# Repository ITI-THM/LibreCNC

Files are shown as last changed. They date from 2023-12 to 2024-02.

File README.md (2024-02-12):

# LibreCNC

## Introduction

LibreCNC is a 100% open source circuit board repository for stepper driver powered CNC Machines of any kind. The circuit boards are designed to be modular with documented interfaces in between the boards.

Please check the [Success Stories](./Success%20Stories/) for a reference on how these boards can be used.

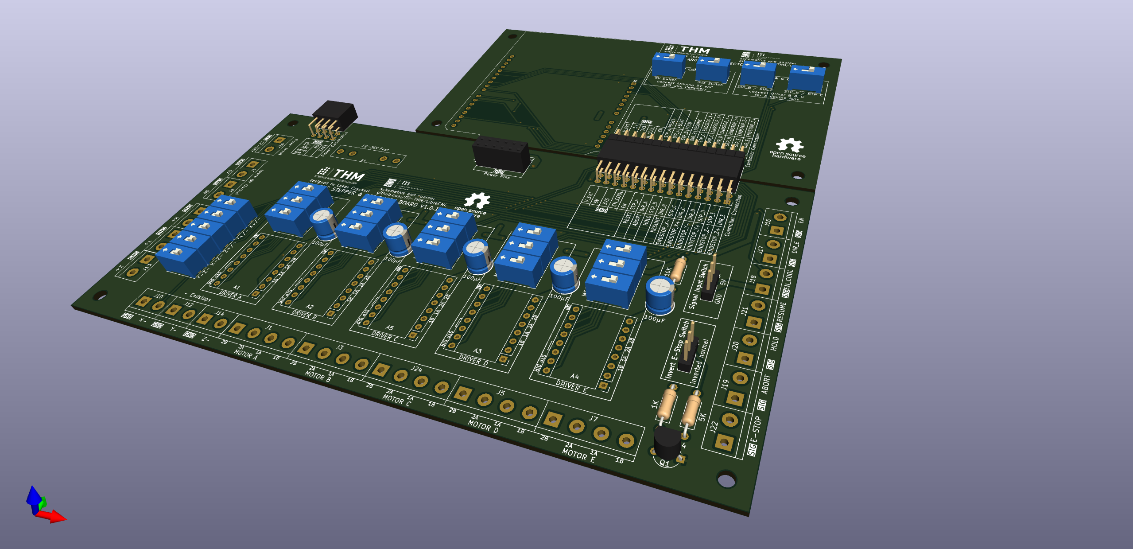
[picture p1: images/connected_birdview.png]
connected_birdview


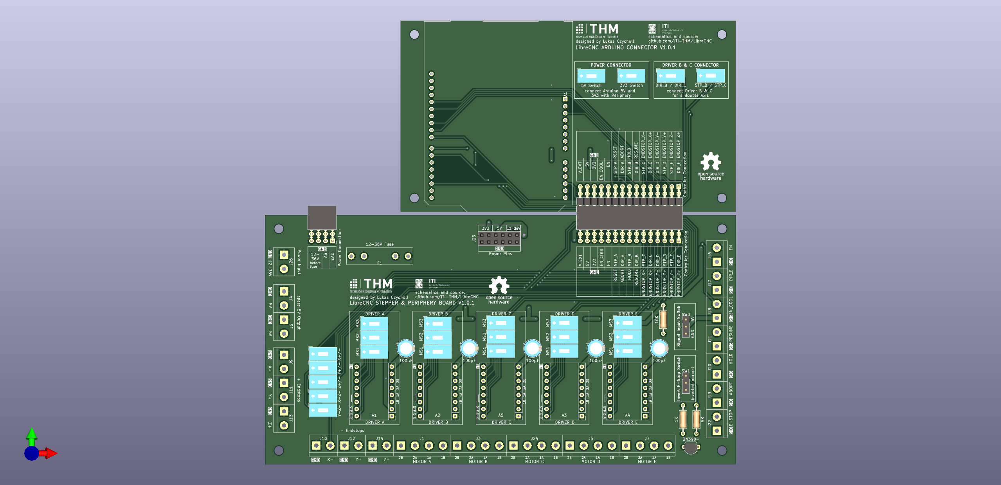
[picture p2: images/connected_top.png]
connected_top


## Circuit Boards

The main modular circuit board is seperated in 3 parts:
- a [periphery board](#periphery-board) for stepper drivers, endstops and buttons
- a [logic board](#logic-board) for a (micro)controller
- a [power board](#power-board) for a stable power supply (tbd)

These parts have fixed interfaces that might be altered whenever a main version is changed (eg. from V1.x to V2.x).

### periphery board

current variations:
- [periphery_5_drivers](./periphery_5_drivers/README.md)

### logic board

current variations:
- [arduino-uno-connector](./arduino-uno-connector/README.md)

### power board

current variations:
None

Additionally these boards were created for specific tasks:
- [arduino pwm fan control board](./fan-control/README.md)

## Repository Structure

Each Circuit Board is designed with [KiCad](https://www.kicad.org/). 

The boards are stored within a directory with the corrsponding name.

Each directory consists of:
- a project file (.kicad_pro)
- a schematic file (.kicad_sch)
- a pcb file (.kicad_pcb)
- a gerber file directory storing gerber files of the finished versions
- a readme giving details about the board
- a picture of a 3D View of the board
- OPTIONAL: a list of parts

## Licencing 

All Circuit Boards are Licenced with the MIT Licence. Feel free to fork and experiment with the schematics and pcbs as you want.

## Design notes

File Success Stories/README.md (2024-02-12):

# Success Stories

This folder holds reference projects to to use as a guideline when using the libreCNC boards

* [Stepcraft 840 V1 Success Story](./Stepcraft%20840/Stepcraft840Story.md)

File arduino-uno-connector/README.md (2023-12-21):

# Arduino Connector

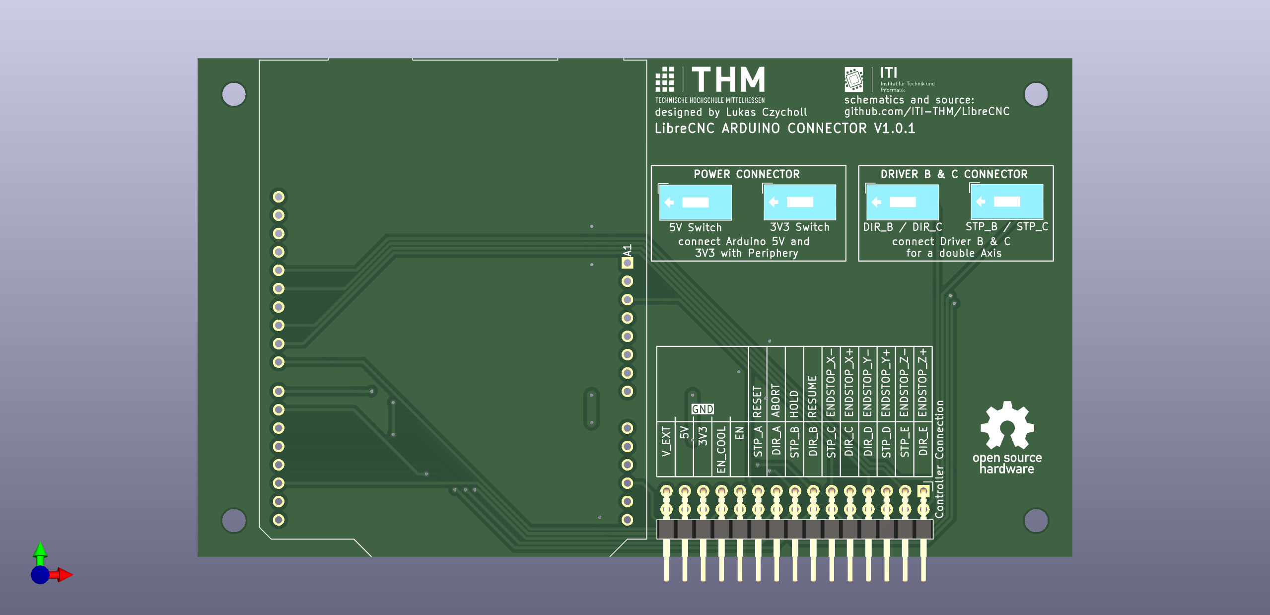
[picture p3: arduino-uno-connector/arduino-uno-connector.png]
arduino-uno-connector


This board is connecting an arduino uno with the periphery board. 
It is designed to be used with [grbl](https://github.com/gnea/grbl) as running software.
Therefore the grbl pinouts are used.

## Driver Usage

- Driver A: X Axis
- Driver B: Y Axis (can be extended with Driver C for a Dual Axis)
- Driver D: Z Axis
- Driver E: Spindle

## Additional Infos

Please be aware of the following things:

- as long as the periphery board has no 5V or 3V3 Input, the 5V and 3V3 of the Arduino can be used.
- the board is designed in a way that the usb port is avaliable at the top of the board. If mounting within limited space be aware that the USB Port is outside the board size.

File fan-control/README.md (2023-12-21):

# arduino pwm fan control

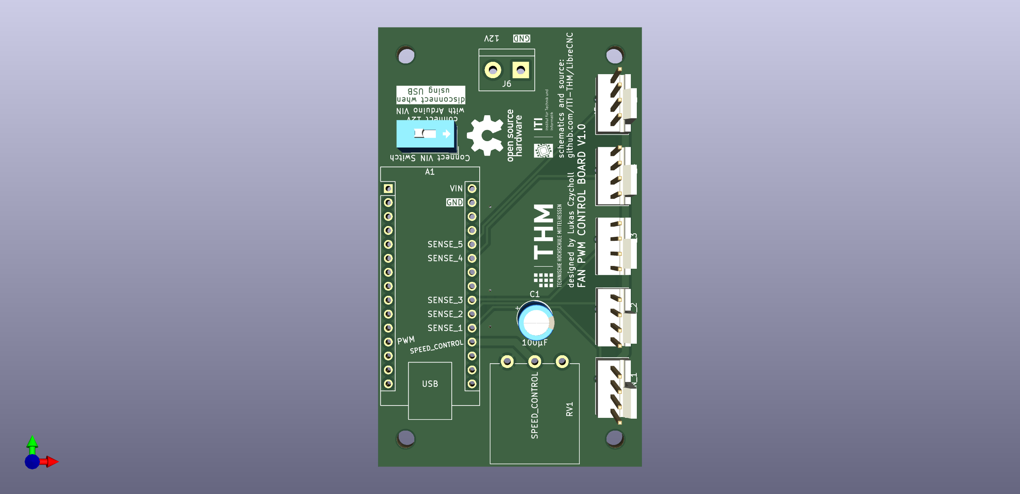
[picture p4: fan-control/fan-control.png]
fan-control


A board designed to hold an arduino nano, a potentiometer and control up to 5 pwm fans

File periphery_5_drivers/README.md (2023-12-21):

# Periphery 5 Drivers

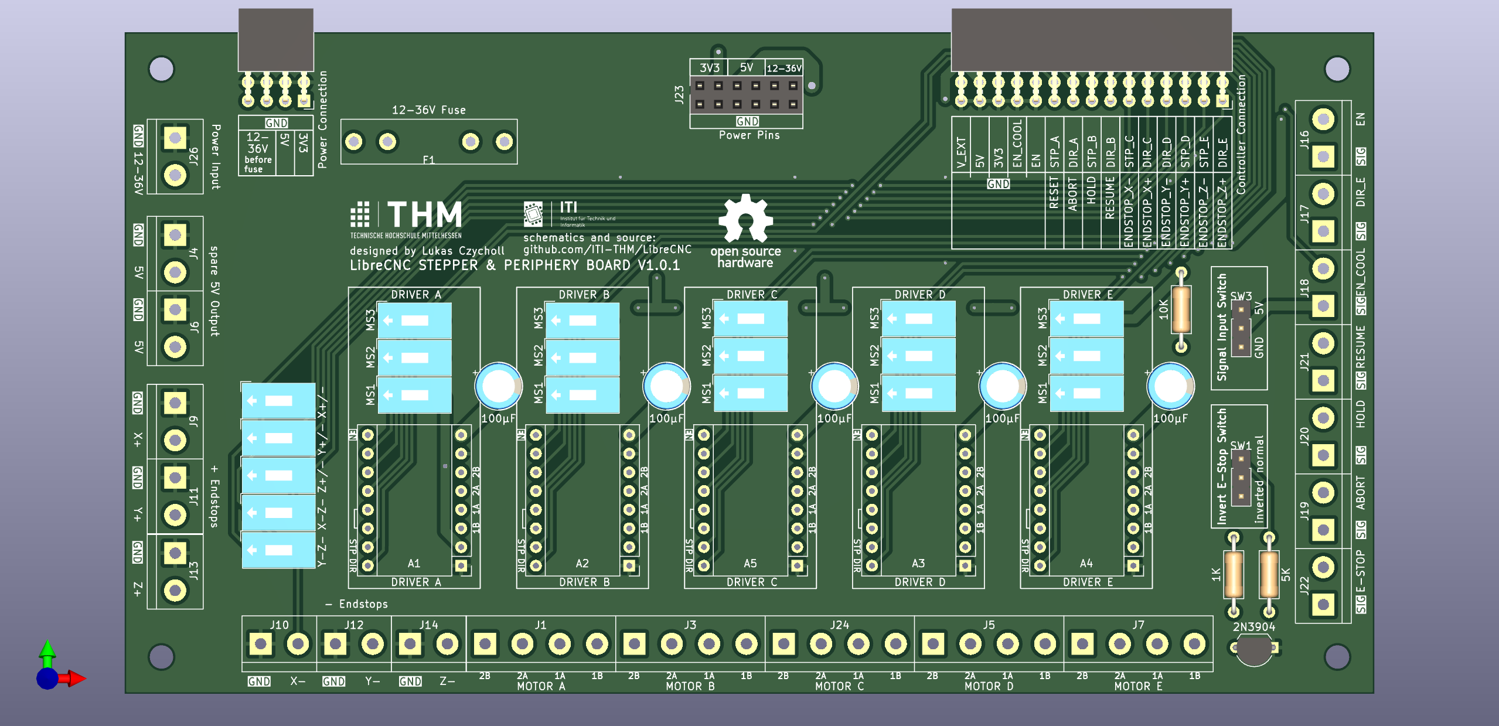
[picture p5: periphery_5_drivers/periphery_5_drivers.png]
periphery_5_drivers


This board is holding periphery for the following:
- 5 stepper drivers
- 6 Endstops
- 5 Buttons
- signal forwarding
- power connections

## stepper drivers

The board is designed for A4988 drivers. 
Therefore any compatabile driver (like the TMC2209) can be used with this board.

## Endstops

the following (basic) endstops are supported:
- X+
- X-
- Y+
- Y-
- Z+
- Z-

Additionally there are switches to connect several endstops in order to be more compatible with different controllers.

- Y- to Z- and X- to Z- can be connected (as it is needed for specific machines)
- X-,Y- & Z- can be connected to the + part to use only one logic signal for both endstops

## Buttons

these buttons are supported:
- E-Stop
- Abort
- Hold
- Resume

The E-Stop signal can be inverted with a hardware switch.

To connect different buttons the signal can be connected to either 5V or GND

## Signal Forwarding

the following signals can be used by external periphery:
- EN
- DIR_E (eg. for an external Spindle)
- EN_COOL (eg. for an external Spindle)

## power connections

### Input: 
When using the periphery board without a power board, the power input screw connection can be used.
This input (as well as the power board input) is secured by a basic fuse.

### Output:
The board has the following power output connections:
- 2x 5V Screw Terminals
- 2x 12-36V Pins
- 2x 5V Pins
- 2x 3V3 Pins

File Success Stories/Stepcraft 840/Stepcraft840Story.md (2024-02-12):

# Stepcraft 840 V1 Success Story
**Replacing the original Board with an OpenSource**

- [Stepcraft 840 V1 Success Story](#stepcraft-840-v1-success-story)
  - [disclaimer](#disclaimer)
  - [Introduction](#introduction)
  - [the default board](#the-default-board)
  - [setting up the libreCNC Board with an arduino UNO](#setting-up-the-librecnc-board-with-an-arduino-uno)
    - [getting everything together](#getting-everything-together)
    - [setting up the board](#setting-up-the-board)
    - [exchanging with the libreCNC Board](#exchanging-with-the-librecnc-board)
  - [setting up the software](#setting-up-the-software)
  - [Conclusion](#conclusion)
  - [Optional: Cover](#optional-cover)
  - [Optional: Fans](#optional-fans)

## disclaimer
altering the Stepcraft 840 with this guide is your responsibility. Please take care of all necessary safety measures and be aware that I as the writer take no responsibility for your health or the health of the machine. Please be aware that your own thinking and basic knowledge and understanding is needed for this guide to be successfull. 

Please also open an issue if you are stuck on any part of this guide or if you were misguided. Thank you for your participation.

## Introduction

The Stepcraft 840 is a hobby milling machine featuring 3 Axis driven by Stepper Drivers, Endstops and (optional) a milling head or any tool. It basically has the same default setup as a 3D Printer.

Currently the Stepcraft 840 is only avaliable in a second revision as the first one had several issues. 
But both versions lack the features of an open source project and thats what this story is changing.

## the default board

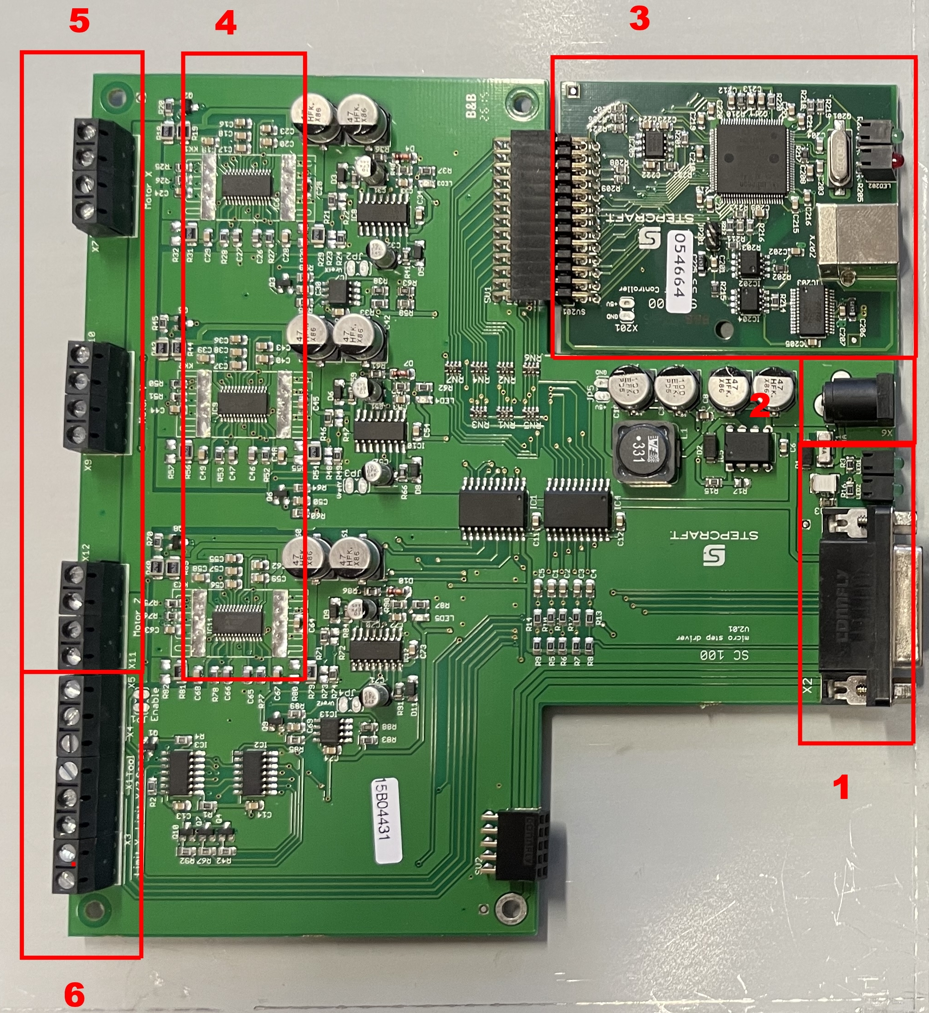
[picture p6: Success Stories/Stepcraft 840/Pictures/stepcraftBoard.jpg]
stepcraft board


When ordering a Stepcraft 840, it ships with a commercial board to control the machine. The board features the following things:

1. RS232 connection for direct communication
2. 12V Barrel Jack Port
3. (optional) USB B Port for indirect communication. (only works with specific software)
4. soldered in stepper drivers
5. 3 stepper driver connections for each axis
6. endstop connections

The board is designed to work with specific proprietary control software which renders the whole board useless if the software is not avaliable or does not satisfy the needs of the user.

## setting up the libreCNC Board with an arduino UNO

### getting everything together
You need the [periphery 5 drivers](../../periphery_5_drivers/README.md) and the [arduino uno connector](../../arduino-uno-connector/README.md) board.

You also need 3 (4 with dual y Axis) stepper drivers. Prefereed are [TMC2208](https://github.com/bigtreetech/BIGTREETECH-TMC2208-V3.0), but any driver with the same basic behavior as the [A4988](https://www.pololu.com/product/1182) works.

With this setup you also need an [Arduino Uno](https://store.arduino.cc/products/arduino-uno-rev3).

### setting up the board

Connect the Arduino Uno with the Arduino Uno Board. You need to enable the Power Connection 5V Switch as this setup only provides the main voltage (12-36V) to the drivers and needs the 5V logical voltage from the arduino.

Then insert the stepper drivers into a, b and c (and d with dual Y Axis) into the slots.

### exchanging with the libreCNC Board

The libreCNC Board Version 1.0.1 is specifically designed to fit within the same slot as the commercial stepcraft board.
It also features almost all peripherals as the commcercial alternative. 

libreCNC & stepcraft comparision

This is how you can connect everything:

* place any non electrically conductive material like a tape on the inside of the metal cover hiding the circuit board within the stepcraft 840.
* 1,2,3: connect the stepper motors from stepcraft x,y,z to libreCNC a,b,d. (if your stepcraft has to y motors, connect the second one to c)
* 4: connect the y endstop connection into y- and the x endstop connection into x-. Also switch the x-/z- switch if no specific cable for the z endstop is avaliable. This means the x and z endstop are connected to the same cable within the milling machine.
* 5: The current libreCNC setup does not provide a Barrel Jack. So instead you need to connect the main Power with screw connectors 

**WARNING: USE AN ELECTRICALLY CONDUCTIVE MATERIAL ON THE INSIDE OF THE METAL COVER**

## setting up the software

With this setup it is preferred to use [grbl](https://github.com/gnea/grbl) to control the machine.

Please use the latest [tutorial](https://github.com/gnea/grbl/wiki/Compiling-Grbl) to set up grbl on the arduino uno.

Optional: 
If you prefer to have a machine that works within a positive coordinate system, you need to change the [config.h](https://github.com/gnea/grbl/blob/master/grbl/config.h) of the grbl software. Make sure to find this part of the config.h:
```
// After homing, Grbl will set by default the entire machine space into negative space, as is typical
// for professional CNC machines, regardless of where the limit switches are located. Uncomment this
// define to force Grbl to always set the machine origin at the homed location despite switch orientation.
#define HOMING_FORCE_SET_ORIGIN // Uncomment to enable.
```

After setting up grbl you need to adjust the grbl configuration by using any serial connection. I prefer using the [Universal G Code Sender](https://github.com/winder/Universal-G-Code-Sender) when using grbl.

This is how the grbl configuration looks like for the setup with the stepcraft 840:
```
$0 = 10    (Step pulse time, microseconds)
$1 = 25    (Step idle delay, milliseconds)
$2 = 0    (Step pulse invert, mask)
$3 = 0    (Step direction invert, mask)
$4 = 0    (Invert step enable pin, boolean)
$5 = 1    (Invert limit pins, boolean)
$6 = 0    (Invert probe pin, boolean)
$10 = 1    (Status report options, mask)
$11 = 0.010    (Junction deviation, millimeters)
$12 = 0.002    (Arc tolerance, millimeters)
$13 = 0    (Report in inches, boolean)
$20 = 0    (Soft limits enable, boolean)
$21 = 0    (Hard limits enable, boolean)
$22 = 1    (Homing cycle enable, boolean)
$23 = 7    (Homing direction invert, mask)
$24 = 250.000    (Homing locate feed rate, mm/min)
$25 = 1000.000    (Homing search seek rate, mm/min)
$26 = 50    (Homing switch debounce delay, milliseconds)
$27 = 1.000    (Homing switch pull-off distance, millimeters)
$30 = 1000    (Maximum spindle speed, RPM)
$31 = 0    (Minimum spindle speed, RPM)
$32 = 0    (Laser-mode enable, boolean)
$100 = 530.000    (X-axis travel resolution, step/mm)
$101 = 530.000    (Y-axis travel resolution, step/mm)
$102 = 530.000    (Z-axis travel resolution, step/mm)
$110 = 1000.000    (X-axis maximum rate, mm/min)
$111 = 1000.000    (Y-axis maximum rate, mm/min)
$112 = 800.000    (Z-axis maximum rate, mm/min)
$120 = 25.000    (X-axis acceleration, mm/sec^2)
$121 = 25.000    (Y-axis acceleration, mm/sec^2)
$122 = 25.000    (Z-axis acceleration, mm/sec^2)
$130 = 600.000    (X-axis maximum travel, millimeters)
$131 = 840.000    (Y-axis maximum travel, millimeters)
$132 = 135.000    (Z-axis maximum travel, millimeters)
```
**WARNING: When wanting to use the machine in negative space make sure $5 and $23 are set to your needs**

## Conclusion

If you reached this point: Congratulations! You made your Stepcraft Open Source. Taste The Freedom of Choice regarding Software. Feel free to adjust the Boards to your needs.

There are a few optional Steps you can do to make your Stepcraft even better

## Optional: Cover

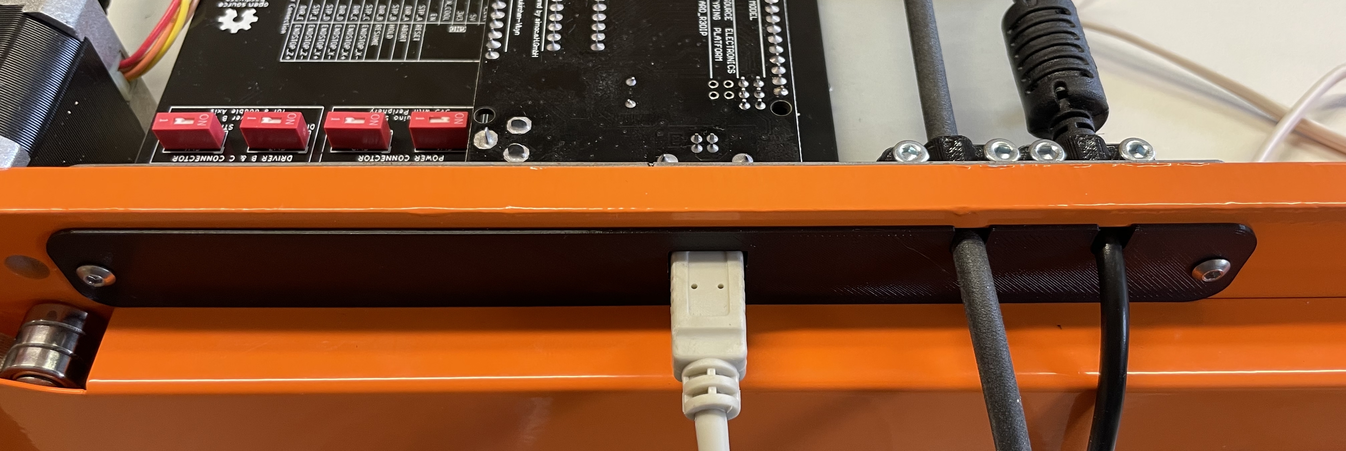
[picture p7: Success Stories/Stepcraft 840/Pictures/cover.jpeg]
cover example setup


There are several Covers avaliable within the [cover folder](./Covers/).

You can choose between 3mf files for printing or a 3fd file for altering with fusion360.

You can also find pictures of the different covers within the folder.

## Optional: Fans

fan example setup

To make sure the stepper drivers are not getting overheated you can use two fans. You can connect the fans to the 5V or 12V output of the periphery board.

To use this fan setup, use the files within the [fan socket](./FanSocket/) folder.

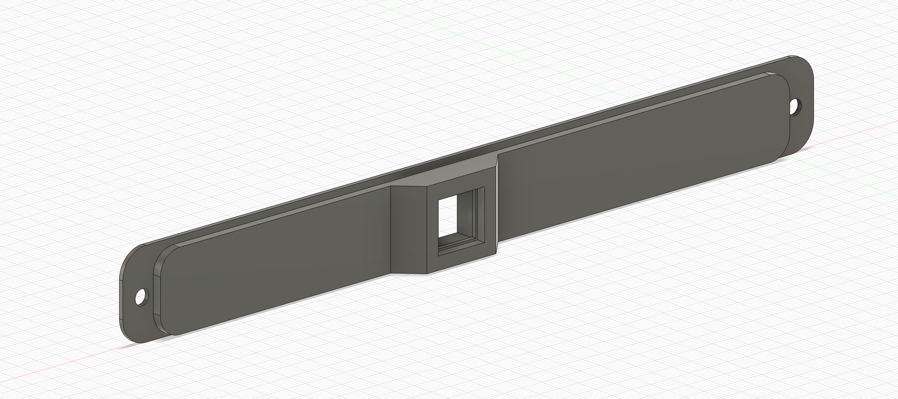
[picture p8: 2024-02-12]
Success Stories/Stepcraft 840/Covers/CoverUno.png

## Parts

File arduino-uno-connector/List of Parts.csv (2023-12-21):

Type | Quantity | Footprint | Designators
Switch | 4 | SW_DIP_SPSTx01_Slide_9.78x4.72mm_W7.62mm_P2.54mm | SW1, SW2, SW3, SW4
Pinheader 2x13 | 1 | PinHeader_2x13_P2.54mm_Horizontal | J1
Pinsocket 1x 10 | 1 | PinSocket_1x10_P2.54mm_Vertical | A1
Pinsocket 1x8 | 2 | PinSocket_1x8_P2.54mm_Vertical | A1
Pinsocket 1x6 | 1 | PinSocket_1x6_P2.54mm_Vertical | A1

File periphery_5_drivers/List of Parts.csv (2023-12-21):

Type | Quantity | Footprint | Designators
Screw Connector 4 Pol | 4 | PhoenixContact_MC_1,5_4-G-5.08_1x04_P5.08mm_Horizontal | J1, J3, J5, J7, J24
Screw Connector 2 Pol | 14 | PhoenixContact_MC_1,5_4-G-5.08_1x04_P5.08mm_Horizontal | J4, J9, J10, J11, J12, J13, J14, J16, J17, J18 J19, J20, J21, J22
Screw Connector 2 Pol Power | 1 | PhoenixContact_MSTBA_2,5_2-G-5,08_1x02_P5.08mm_Horizontal | J26
Pinsocket 2x13 | 1 | PinSocket_2x13_P2.54mm_Horizontal | J27
Pinsocket 2x2 | 1 | PinSocket_2x2_P2.54mm_Horizontal | J6
Pinheader 2x6 | 1 | PinHeader_2x06_P2.54mm_Vertical | J23
Pinsocket 1x8 | 10 |  | A1, A2, A3, A4, A5
Fuse Socket | 1 | Fuseholder_Littelfuse_100_series_5x20mm | F1
Switch 2 Pin | 12 | SW_DIP_SPSTx01_Slide_9.78x4.72mm_W7.62mm_P2.54mm | SW4, SW5, SW6, SW7, SW8, SW9, SW10, SW11, SW12, SW13, SW14, SW15
Switch 3 Pin | 2 |  | SW1, SW3
Resistor 1K | 1 | R_Axial_DIN0204_L3.6mm_D1.6mm_P7.62mm_Horizontal | R3
Resistor 5K | 1 | R_Axial_DIN0204_L3.6mm_D1.6mm_P7.62mm_Horizontal | R2
Resistor 10K | 1 | R_Axial_DIN0204_L3.6mm_D1.6mm_P7.62mm_Horizontal | R1
Transistor 2N3904 | 1 | TO-92_Inline | Q1
Capacitor 100µF | 5 | CP_Radial_D6.3mm_P2.50mm | C1, C2, C3, C4, C5

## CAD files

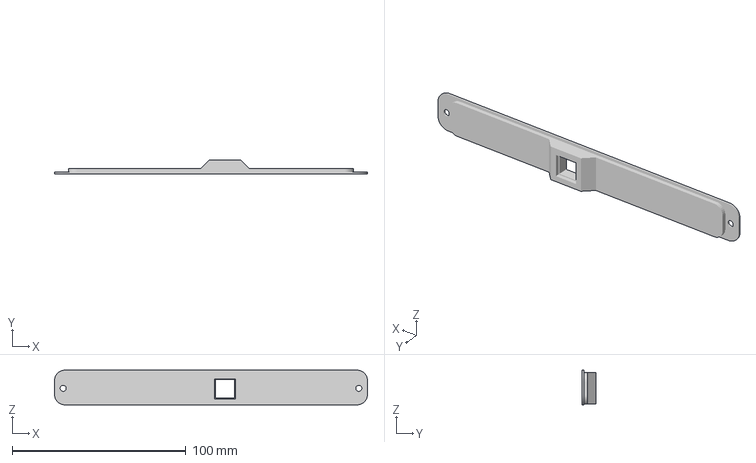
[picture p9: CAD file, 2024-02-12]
Success Stories/Stepcraft 840/Covers/CoverUno.3mf
180.0 x 8.00 x 20.0 mm

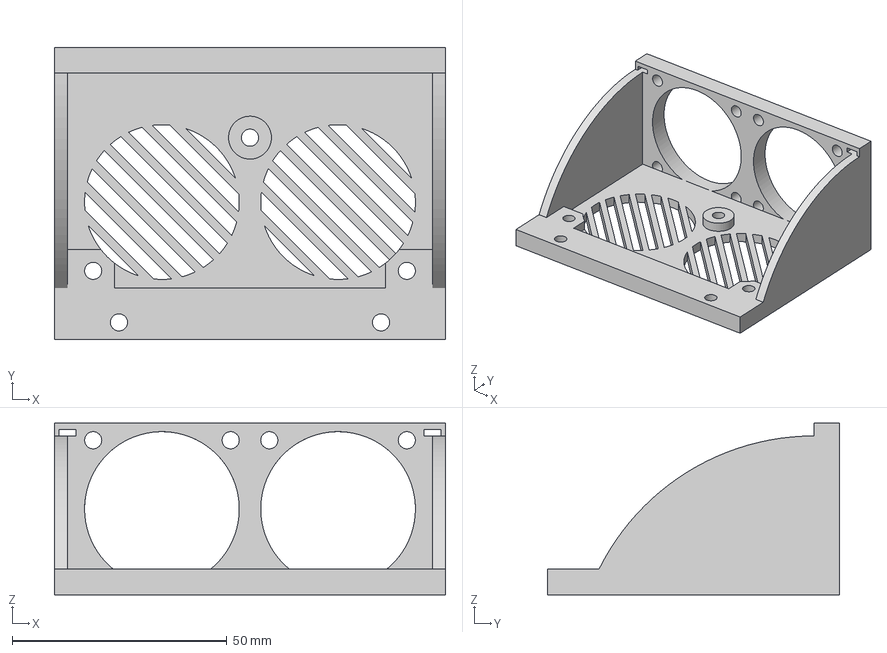
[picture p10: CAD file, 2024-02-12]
Success Stories/Stepcraft 840/FanSocket/fanSocket.3mf
91.0 x 68.0 x 40.0 mm

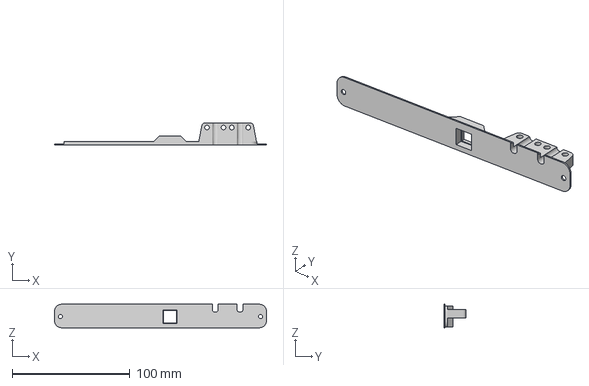
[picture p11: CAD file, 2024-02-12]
Success Stories/Stepcraft 840/Covers/CoverWithCables.3mf
180.0 x 19.0 x 20.0 mm

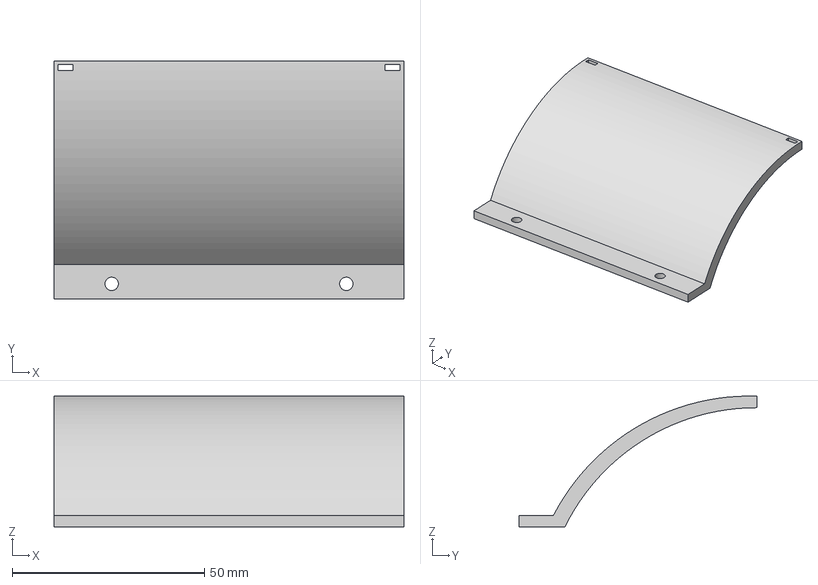
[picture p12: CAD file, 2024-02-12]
Success Stories/Stepcraft 840/FanSocket/fanSocketLid.3mf
91.0 x 62.0 x 34.0 mm

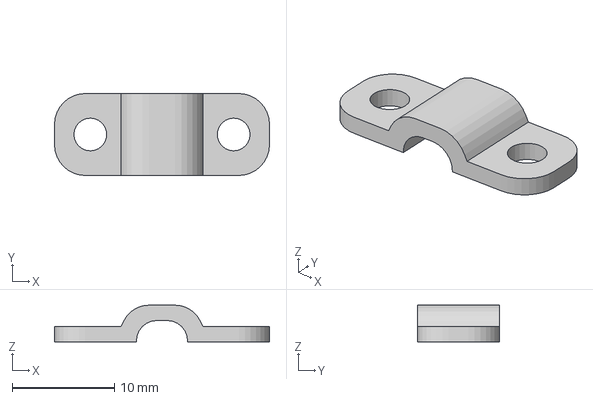
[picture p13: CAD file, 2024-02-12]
Success Stories/Stepcraft 840/Covers/CoverCableClam.3mf
21.0 x 8.00 x 3.59 mm

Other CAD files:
Success Stories/Stepcraft 840/Covers/CoverUno.f3d
Success Stories/Stepcraft 840/Covers/CoverWithCables.f3d
Success Stories/Stepcraft 840/FanSocket/fanSocket.f3d

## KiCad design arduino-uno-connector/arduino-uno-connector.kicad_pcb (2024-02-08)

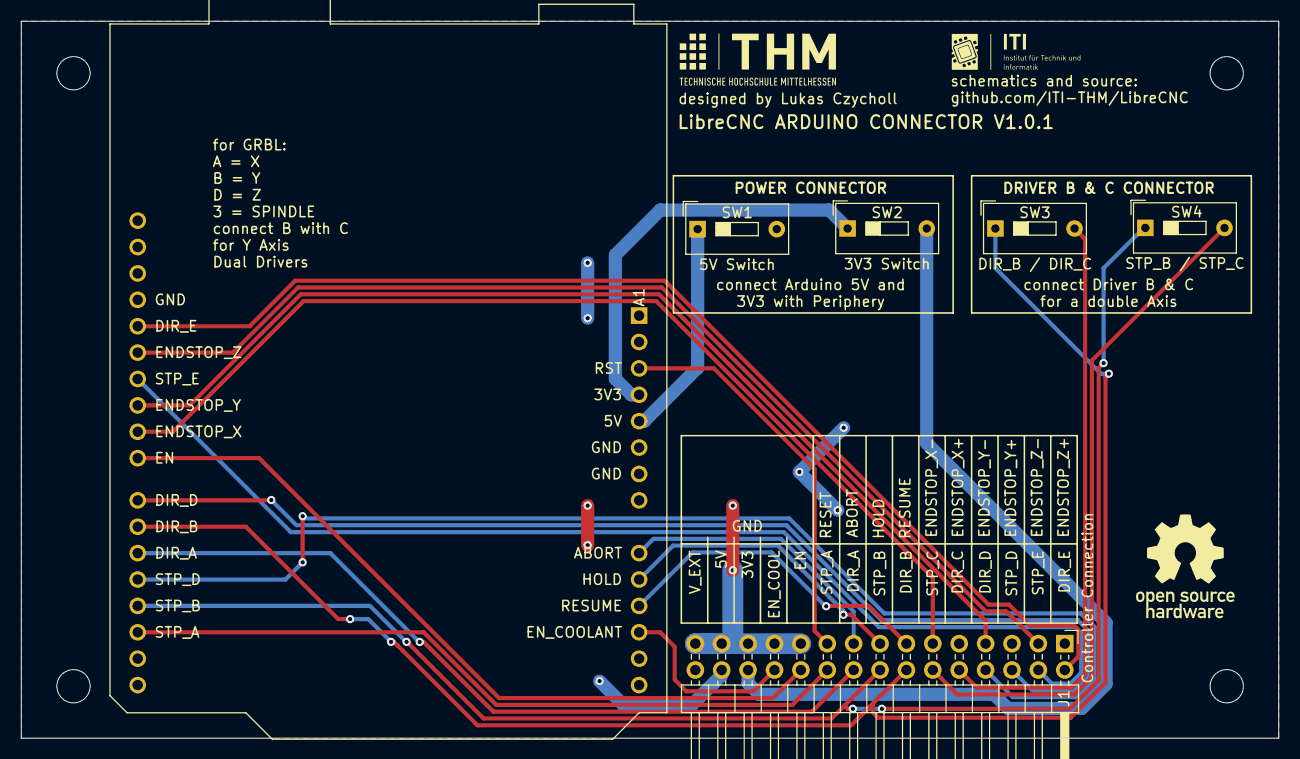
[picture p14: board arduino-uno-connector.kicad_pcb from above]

Board: 2 copper layers, 121.0 x 69.0 mm, 10 parts (0 on the bottom side), 24 nets.

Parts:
A1: Arduino_UNO_R3
H1, H2, H3: MountingHole; MountingHole_3.2mm_M3
J1: Controller Connection; PinHeader_2x15_P2.54mm_Horizontal
SW1: 5V Switch; SW_DIP_SPSTx01_Slide_9.78x4.72mm_W7.62mm_P2.54mm
SW2: 3V3 Switch; SW_DIP_SPSTx01_Slide_9.78x4.72mm_W7.62mm_P2.54mm
SW3: DIR_B / DIR_C; SW_DIP_SPSTx01_Slide_9.78x4.72mm_W7.62mm_P2.54mm
SW4: STP_B / STP_C; SW_DIP_SPSTx01_Slide_9.78x4.72mm_W7.62mm_P2.54mm
locked: MountingHole; MountingHole_3.2mm_M3

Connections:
3V3: J1.26, SW2.2 (B)
3V3_Controller: A1.4 (3V3), SW2.1 (A)
5V: J1.28, SW1.2 (B)
5V_Controller: A1.5 (+5V), SW1.1 (A)
ABORT: A1.9 (A0), J1.17
DIR_A: A1.20 (D5), J1.18
DIR_B: A1.21 (D6), J1.14, SW3.1 (A)
DIR_C: J1.10, SW3.2 (B)
DIR_D: A1.22 (D7), J1.6
DIR_E: A1.28 (D13), J1.2
EN: A1.23 (D8), J1.22
ENDSTOP_X-: A1.24 (D9), J1.11
ENDSTOP_Y-: A1.25 (D10), J1.7
ENDSTOP_Z-: A1.27 (D12), J1.3
EN_COOLANT: A1.12 (A3), J1.24
GND: A1.6 (GND), A1.7 (GND), A1.29 (GND), J1.21, J1.23, J1.25, J1.27, J1.29
HOLD: A1.10 (A1), J1.15
RESUME: A1.11 (A2), J1.13
RST: A1.3 (~RESET), J1.19
STP_A: A1.17 (D2), J1.20
STP_B: A1.18 (D3), J1.16, SW4.1 (A)
STP_C: J1.12, SW4.2 (B)
STP_D: A1.19 (D4), J1.8
STP_E: A1.26 (D11), J1.4

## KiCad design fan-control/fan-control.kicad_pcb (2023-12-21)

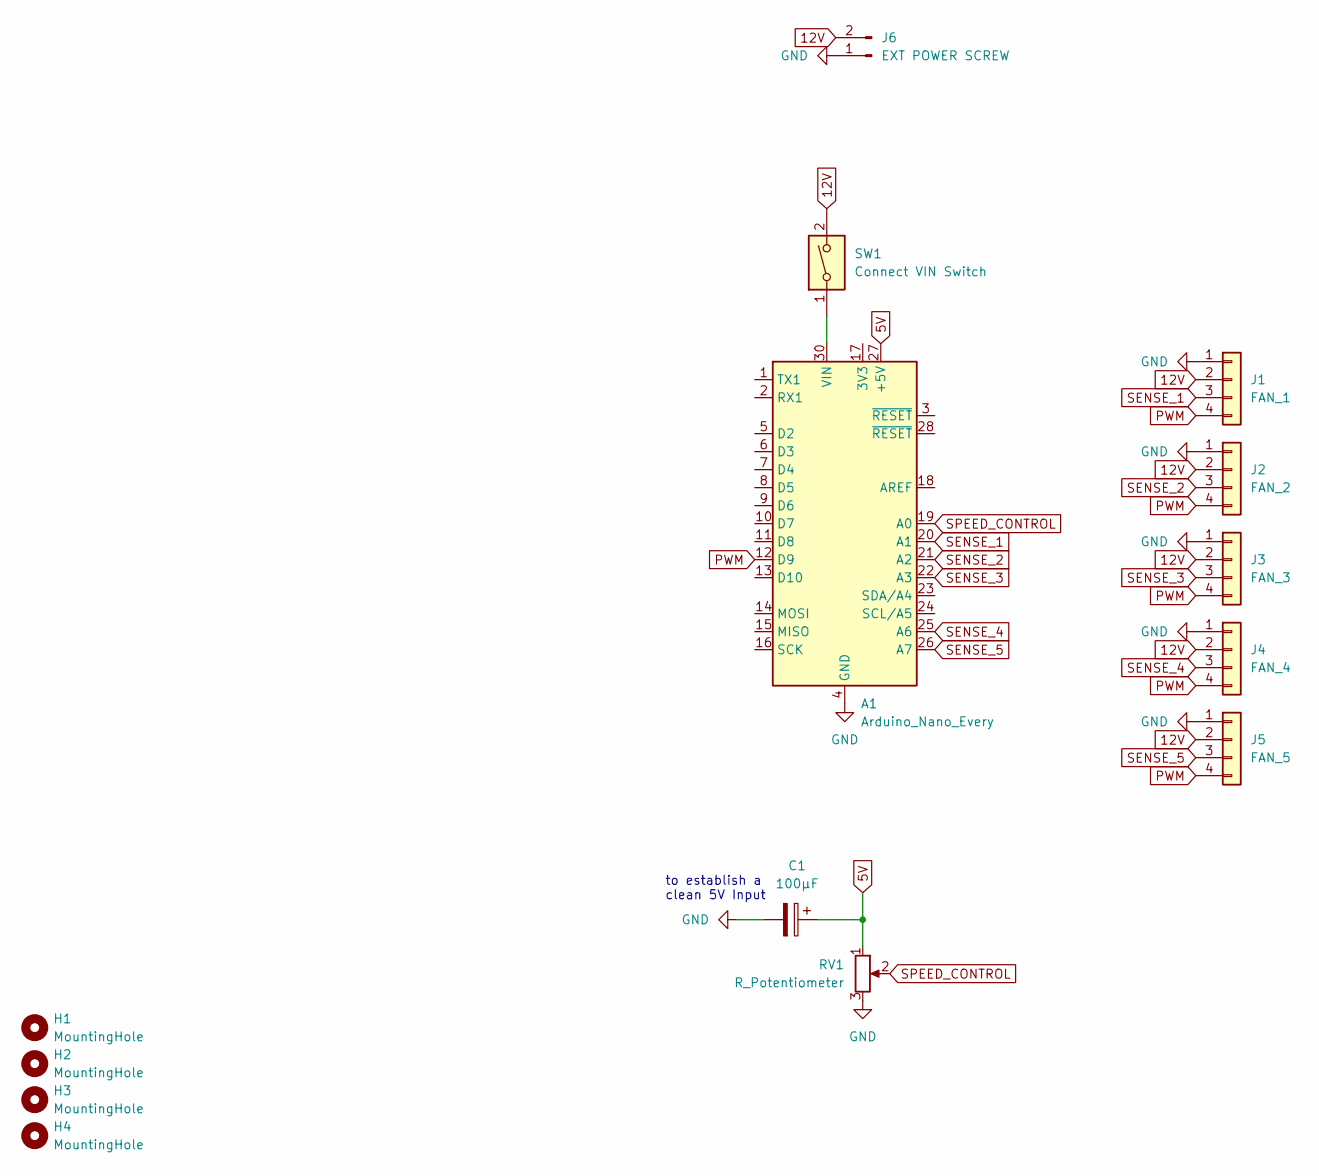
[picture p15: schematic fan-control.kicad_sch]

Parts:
A1: Arduino_Nano_Every; Arduino_Nano
C1: 100µF; CP_Radial_D6.3mm_P2.50mm
H1, H2, H3, H4: MountingHole; MountingHole_3.2mm_M3
J1: FAN_1; FanPinHeader_1x04_P2.54mm_Vertical
J2: FAN_2; FanPinHeader_1x04_P2.54mm_Vertical
J3: FAN_3; FanPinHeader_1x04_P2.54mm_Vertical
J4: FAN_4; FanPinHeader_1x04_P2.54mm_Vertical
J5: FAN_5; FanPinHeader_1x04_P2.54mm_Vertical
J6: EXT POWER SCREW; TerminalBlock_bornier-2_P5.08mm
RV1: R_Potentiometer; Potentiometer_Piher_PC-16_Single_Vertical
SW1: Connect VIN Switch; SW_DIP_SPSTx01_Slide_9.78x4.72mm_W7.62mm_P2.54mm

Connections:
5V: A1.27 (+5V), C1.1, RV1.1
12V: J1.2, J2.2, J3.2, J4.2, J5.2, J6.2, SW1.2
GND: A1.4 (GND), A1.29 (GND), C1.2, J1.1, J2.1, J3.1, J4.1, J5.1, J6.1, RV1.3
unnamed: A1.30 (VIN), SW1.1
PWM: A1.12 (D9), J1.4, J2.4, J3.4, J4.4, J5.4
SENSE_1: A1.20 (A1), J1.3
SENSE_2: A1.21 (A2), J2.3
SENSE_3: A1.22 (A3), J3.3
SENSE_4: A1.25 (A6), J4.3
SENSE_5: A1.26 (A7), J5.3
SPEED_CONTROL: A1.19 (A0), RV1.2

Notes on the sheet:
to establish a clean 5V Input

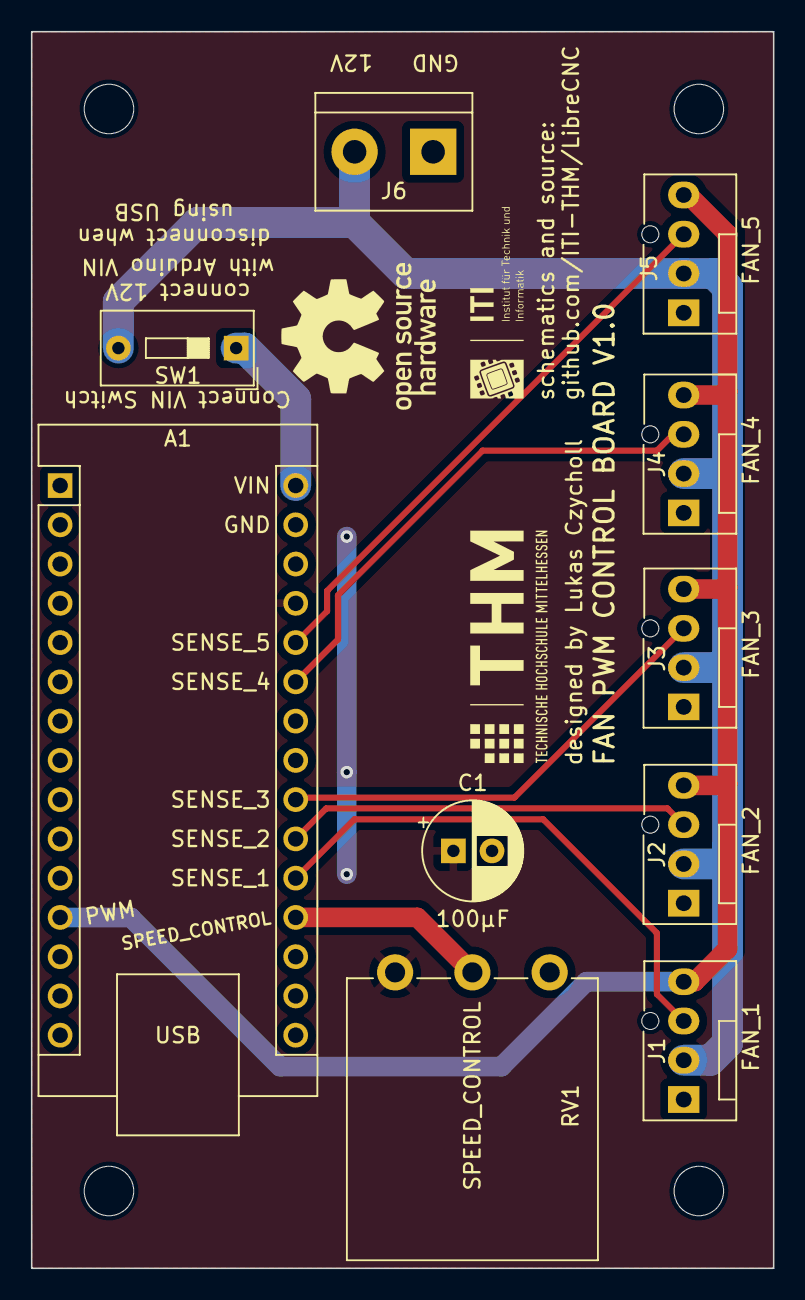
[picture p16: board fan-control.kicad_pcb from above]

Board: 2 copper layers, 48.0 x 80.0 mm, 14 parts (0 on the bottom side), 11 nets.

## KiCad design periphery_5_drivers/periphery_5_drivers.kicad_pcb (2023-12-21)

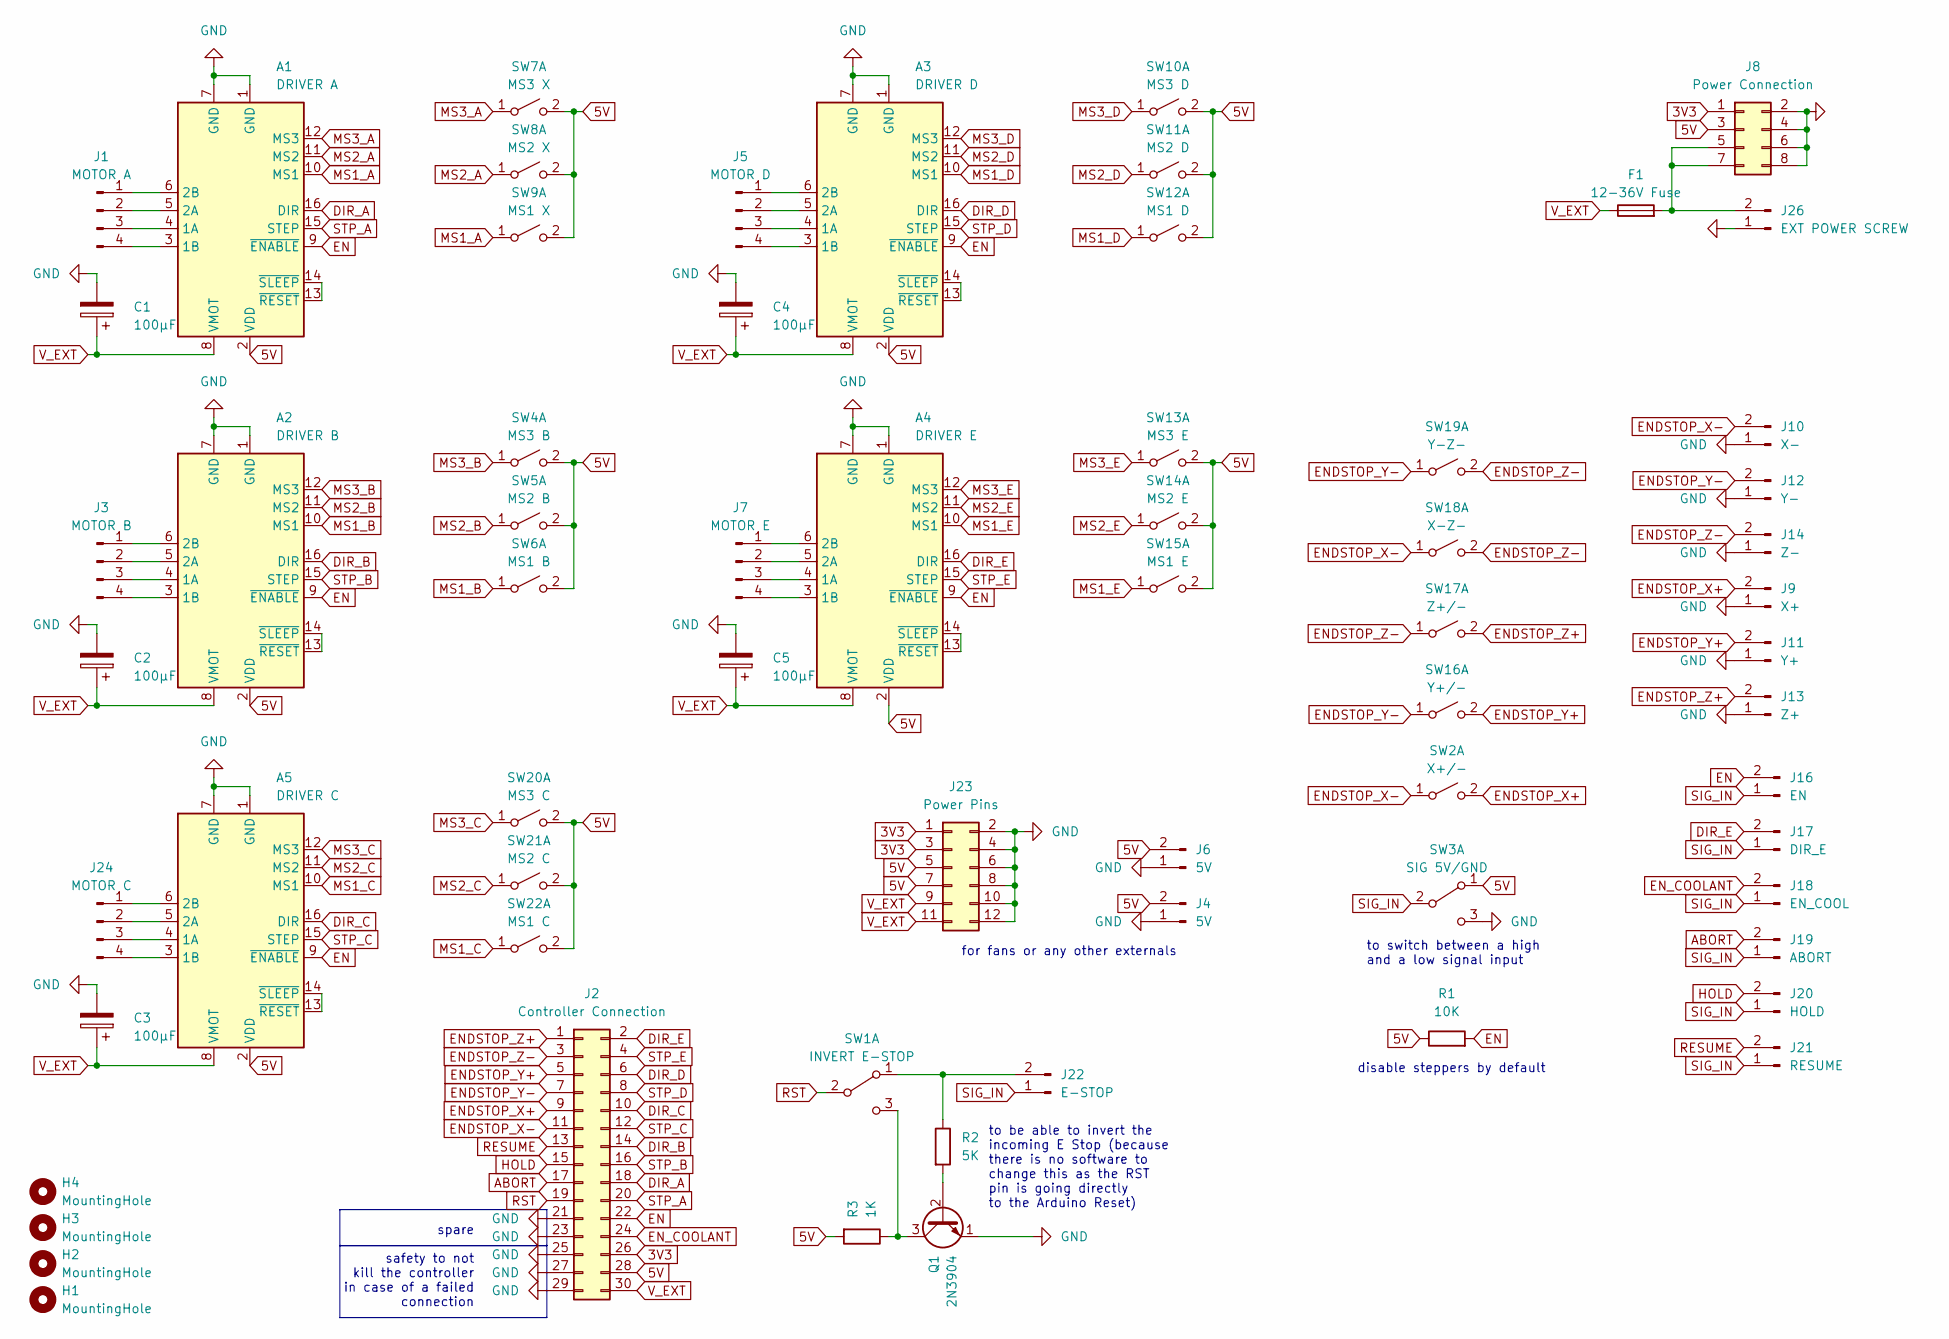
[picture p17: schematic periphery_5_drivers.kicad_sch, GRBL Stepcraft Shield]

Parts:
A1: DRIVER A; Pololu_Breakout-16_15.2x20.3mm
A2: DRIVER B; Pololu_Breakout-16_15.2x20.3mm
A3: DRIVER D; Pololu_Breakout-16_15.2x20.3mm
A4: DRIVER E; Pololu_Breakout-16_15.2x20.3mm
A5: DRIVER C; Pololu_Breakout-16_15.2x20.3mm
C1, C2, C3, C4, C5: 100µF; CP_Radial_D6.3mm_P2.50mm
F1: 12-36V Fuse; Fuseholder_Littelfuse_100_series_5x20mm
H1, H2, H3, H4: MountingHole; MountingHole_3.2mm_M3
J1: MOTOR A; TerminalBlock_bornier-4_P5.08mm
J2: Controller Connection; PinSocket_2x15_P2.54mm_Horizontal
J3: MOTOR B; TerminalBlock_bornier-4_P5.08mm
J4, J6: 5V; TerminalBlock_bornier-2_P5.08mm
J5: MOTOR D; TerminalBlock_bornier-4_P5.08mm
J7: MOTOR E; TerminalBlock_bornier-4_P5.08mm
J8: Power Connection; PinSocket_2x04_P2.54mm_Horizontal
J9: X+; TerminalBlock_bornier-2_P5.08mm
J10: X-; TerminalBlock_bornier-2_P5.08mm
J11: Y+; TerminalBlock_bornier-2_P5.08mm
J12: Y-; TerminalBlock_bornier-2_P5.08mm
J13: Z+; TerminalBlock_bornier-2_P5.08mm
J14: Z-; TerminalBlock_bornier-2_P5.08mm
J16: EN; TerminalBlock_bornier-2_P5.08mm
J17: DIR_E; TerminalBlock_bornier-2_P5.08mm
J18: EN_COOL; TerminalBlock_bornier-2_P5.08mm
J19: ABORT; TerminalBlock_bornier-2_P5.08mm
J20: HOLD; TerminalBlock_bornier-2_P5.08mm
J21: RESUME; TerminalBlock_bornier-2_P5.08mm
J22: E-STOP; TerminalBlock_bornier-2_P5.08mm
J23: Power Pins; PinSocket_2x06_P2.54mm_Vertical
J24: MOTOR C; TerminalBlock_bornier-4_P5.08mm
J26: EXT POWER SCREW; TerminalBlock_bornier-2_P5.08mm
Q1: 2N3904; TO-92_Inline_Wide
R1: 10K; R_Axial_DIN0207_L6.3mm_D2.5mm_P10.16mm_Horizontal
R2: 5K; R_Axial_DIN0207_L6.3mm_D2.5mm_P10.16mm_Horizontal
R3: 1K; R_Axial_DIN0207_L6.3mm_D2.5mm_P10.16mm_Horizontal
SW1: INVERT E-STOP; PinHeader_1x03_P2.54mm_Vertical
SW2: X+/-; SW_DIP_SPSTx01_Slide_9.78x4.72mm_W7.62mm_P2.54mm
SW3: SIG 5V/GND; PinHeader_1x03_P2.54mm_Vertical
SW4: MS3 B; SW_DIP_SPSTx01_Slide_9.78x4.72mm_W7.62mm_P2.54mm
SW5: MS2 B; SW_DIP_SPSTx01_Slide_9.78x4.72mm_W7.62mm_P2.54mm
SW6: MS1 B; SW_DIP_SPSTx01_Slide_9.78x4.72mm_W7.62mm_P2.54mm
SW7: MS3 X; SW_DIP_SPSTx01_Slide_9.78x4.72mm_W7.62mm_P2.54mm
SW8: MS2 X; SW_DIP_SPSTx01_Slide_9.78x4.72mm_W7.62mm_P2.54mm
SW9: MS1 X; SW_DIP_SPSTx01_Slide_9.78x4.72mm_W7.62mm_P2.54mm
SW10: MS3 D; SW_DIP_SPSTx01_Slide_9.78x4.72mm_W7.62mm_P2.54mm
SW11: MS2 D; SW_DIP_SPSTx01_Slide_9.78x4.72mm_W7.62mm_P2.54mm
SW12: MS1 D; SW_DIP_SPSTx01_Slide_9.78x4.72mm_W7.62mm_P2.54mm
SW13: MS3 E; SW_DIP_SPSTx01_Slide_9.78x4.72mm_W7.62mm_P2.54mm
SW14: MS2 E; SW_DIP_SPSTx01_Slide_9.78x4.72mm_W7.62mm_P2.54mm
SW15: MS1 E; SW_DIP_SPSTx01_Slide_9.78x4.72mm_W7.62mm_P2.54mm
SW16: Y+/-; SW_DIP_SPSTx01_Slide_9.78x4.72mm_W7.62mm_P2.54mm
SW17: Z+/-; SW_DIP_SPSTx01_Slide_9.78x4.72mm_W7.62mm_P2.54mm
SW18: X-Z-; SW_DIP_SPSTx01_Slide_9.78x4.72mm_W7.62mm_P2.54mm
SW19: Y-Z-; SW_DIP_SPSTx01_Slide_9.78x4.72mm_W7.62mm_P2.54mm
SW20: MS3 C; SW_DIP_SPSTx01_Slide_9.78x4.72mm_W7.62mm_P2.54mm
SW21: MS2 C; SW_DIP_SPSTx01_Slide_9.78x4.72mm_W7.62mm_P2.54mm
SW22: MS1 C; SW_DIP_SPSTx01_Slide_9.78x4.72mm_W7.62mm_P2.54mm

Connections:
3V3: J2.26, J8.1, J23.1, J23.3
5V: A1.2 (VDD), A2.2 (VDD), A3.2 (VDD), A4.2 (VDD), A5.2 (VDD), J2.28, J4.2, J6.2, J8.3, J23.5, J23.7, R1.1, R3.2, SW3.1 (A), SW4.2 (B), SW5.2 (B), SW6.2 (B), SW7.2 (B), SW8.2 (B), SW9.2 (B), SW10.2 (B), SW11.2 (B), SW12.2 (B), SW13.2 (B), SW14.2 (B), SW15.2 (B), SW20.2 (B), SW21.2 (B), SW22.2 (B)
ABORT: J2.17, J19.2
DIR_A: A1.16 (DIR), J2.18
DIR_B: A2.16 (DIR), J2.14
DIR_C: A5.16 (DIR), J2.10
DIR_D: A3.16 (DIR), J2.6
DIR_E: A4.16 (DIR), J2.2, J17.2
EN: A1.9 (~ENABLE), A2.9 (~ENABLE), A3.9 (~ENABLE), A4.9 (~ENABLE), A5.9 (~ENABLE), J2.22, J16.2, R1.2
ENDSTOP_X+: J2.9, J9.2, SW2.2 (B)
ENDSTOP_X-: J2.11, J10.2, SW2.1 (A), SW18.1 (A)
ENDSTOP_Y+: J2.5, J11.2, SW16.2 (B)
ENDSTOP_Y-: J2.7, J12.2, SW16.1 (A), SW19.1 (A)
ENDSTOP_Z+: J2.1, J13.2, SW17.2 (B)
ENDSTOP_Z-: J2.3, J14.2, SW17.1 (A), SW18.2 (B), SW19.2 (B)
EN_COOLANT: J2.24, J18.2
GND: A1.1 (GND), A1.7 (GND), A2.1 (GND), A2.7 (GND), A3.1 (GND), A3.7 (GND), A4.1 (GND), A4.7 (GND), A5.1 (GND), A5.7 (GND), C1.2, C2.2, C3.2, C4.2, C5.2, J2.21, J2.23, J2.25, J2.27, J2.29, J4.1, J6.1, J8.2, J8.4, J8.6, J8.8, J9.1, J10.1, J11.1, J12.1, J13.1, J14.1, J23.2, J23.4, J23.6, J23.8, J23.10, J23.12, J26.1, Q1.1 (E), SW3.3 (C)
HOLD: J2.15, J20.2
MS1_A: A1.10 (MS1), SW9.1 (A)
MS1_B: A2.10 (MS1), SW6.1 (A)
MS1_C: A5.10 (MS1), SW22.1 (A)
MS1_D: A3.10 (MS1), SW12.1 (A)
MS1_E: A4.10 (MS1), SW15.1 (A)
MS2_A: A1.11 (MS2), SW8.1 (A)
MS2_B: A2.11 (MS2), SW5.1 (A)
MS2_C: A5.11 (MS2), SW21.1 (A)
MS2_D: A3.11 (MS2), SW11.1 (A)
MS2_E: A4.11 (MS2), SW14.1 (A)
MS3_A: A1.12 (MS3), SW7.1 (A)
MS3_B: A2.12 (MS3), SW4.1 (A)
MS3_C: A5.12 (MS3), SW20.1 (A)
MS3_D: A3.12 (MS3), SW10.1 (A)
MS3_E: A4.12 (MS3), SW13.1 (A)
unnamed: A1.4 (1A), J1.3
unnamed: A1.3 (1B), J1.4
unnamed: A1.5 (2A), J1.2
unnamed: A1.6 (2B), J1.1
unnamed: A1.13 (~RESET), A1.14 (~SLEEP)
unnamed: A2.4 (1A), J3.3
unnamed: A2.3 (1B), J3.4
unnamed: A2.5 (2A), J3.2
unnamed: A2.6 (2B), J3.1
unnamed: A2.13 (~RESET), A2.14 (~SLEEP)
unnamed: A3.4 (1A), J5.3
unnamed: A3.3 (1B), J5.4
unnamed: A3.5 (2A), J5.2
unnamed: A3.6 (2B), J5.1
unnamed: A3.13 (~RESET), A3.14 (~SLEEP)
unnamed: A4.4 (1A), J7.3
unnamed: A4.3 (1B), J7.4
unnamed: A4.5 (2A), J7.2
unnamed: A4.6 (2B), J7.1
unnamed: A4.13 (~RESET), A4.14 (~SLEEP)
unnamed: A5.4 (1A), J24.3
unnamed: A5.3 (1B), J24.4
unnamed: A5.5 (2A), J24.2
unnamed: A5.6 (2B), J24.1
unnamed: A5.13 (~RESET), A5.14 (~SLEEP)
unnamed: J22.2, R2.1, SW1.1 (A)
unnamed: F1.2, J8.5, J8.7, J26.2
unnamed: Q1.2 (B), R2.2
unnamed: Q1.3 (C), R3.1, SW1.3 (C)
RESUME: J2.13, J21.2
RST: J2.19, SW1.2 (B)
SIG_IN: J16.1, J17.1, J18.1, J19.1, J20.1, J21.1, J22.1, SW3.2 (B)
STP_A: A1.15 (STEP), J2.20
STP_B: A2.15 (STEP), J2.16
STP_C: A5.15 (STEP), J2.12
STP_D: A3.15 (STEP), J2.8
STP_E: A4.15 (STEP), J2.4
V_EXT: A1.8 (VMOT), A2.8 (VMOT), A3.8 (VMOT), A4.8 (VMOT), A5.8 (VMOT), C1.1, C2.1, C3.1, C4.1, C5.1, F1.1, J2.30, J23.9, J23.11

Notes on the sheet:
safety to not kill the controller in case of a failed connection
for fans or any other externals
to be able to invert the incoming E Stop (because there is no software to change this as the RST pin is going directly to the Arduino Reset)
spare
to switch between a high and a low signal input
disable steppers by default

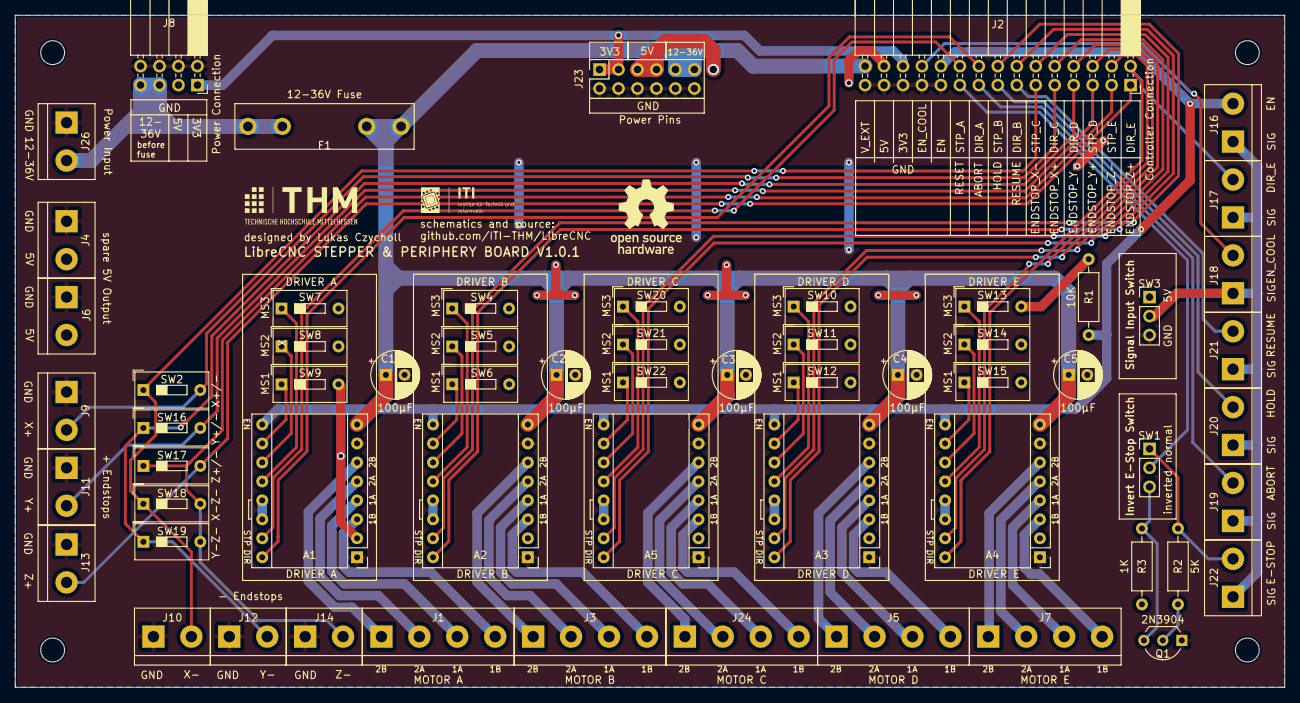
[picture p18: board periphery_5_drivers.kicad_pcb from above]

Board: 2 copper layers, 170.0 x 90.0 mm, 65 parts (0 on the bottom side), 71 nets.

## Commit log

2023-12-21 Adding Circuit Board KiCad Files, Altered gitignore
    [List of Parts.csv, arduino-connector.kicad_pcb, arduino-connector.kicad_sch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]
2023-12-21 Added Gerber Files for each Circuit Board
    [arduino-connector.kicad_pcb, fan-control.kicad_pcb, periphery_5_drivers.kicad_pcb]
2023-12-21 added readmes and updated naming of arduino connector
    [List of Parts.csv, arduino-uno-connector.kicad_pcb, arduino-uno-connector.kicad_sch]
2024-01-02 added drill holes
    [arduino-uno-connector-B_Cu.gbr, arduino-uno-connector-B_Mask.gbr, arduino-uno-connector-B_Paste.gbr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]
2024-02-08 Updated Printing for Arduino and GRBL Reference
    [arduino-uno-connector.kicad_pcb, arduino-uno-connector.kicad_sch]
2024-02-12 Added a Success Story
    [fanSocket.3mf, fanSocket.f3d, fanSocketLid.3mf]
2024-02-12 updated the success story with a cover section
    [CoverCableClam.3mf, CoverUno.3mf, CoverUno.f3d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]
2024-02-12 fixed the relative links for fan section Added a table of contents
2024-02-12 cleaned up the success story folder
    [CoverWithCables.f3d]
2024-02-12 updated z maximum travel option for grbl
